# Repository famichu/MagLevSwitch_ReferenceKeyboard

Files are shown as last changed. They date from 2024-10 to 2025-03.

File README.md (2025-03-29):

# MagLev Switch Reference Keyboard
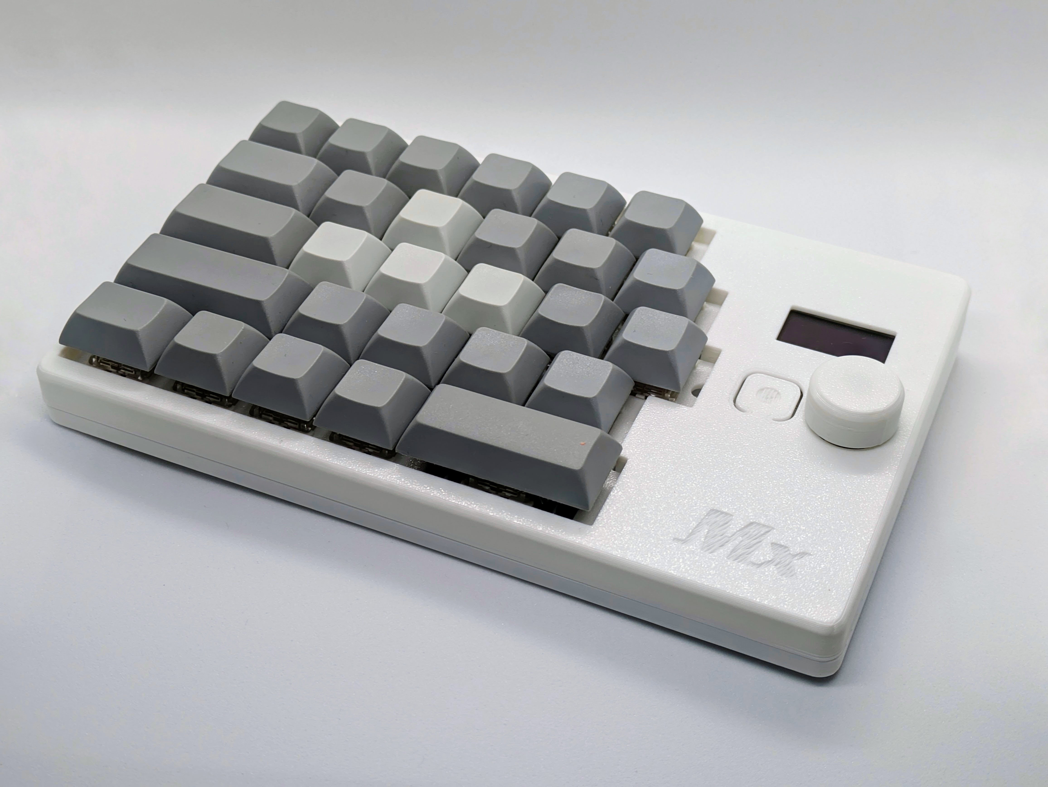
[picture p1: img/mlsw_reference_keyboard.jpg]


## Summary
This keyboard is a reference keyboard for using the MagLev switch, which has linear-output Hall effect sensors and magnetic levitation switches.

## Features
- A 28-switches keyboard for the left hand
- Uses 4 MagLev switches for the WASD keys
- Able to read the depth of the MagLev switches
- Built-in OLED displaying MagLev switch depth graphs

## BOM
### Main PCB
- Main PCB x1
- Kailh Switch Socket x24
- Cherry MX compatible switch x24
- MagLev Switch MX x4
- Stabilizer(2U) x2
- Incremental rotary encoder(PEC12R series of compatible) x1
- RP2040 x1
- Other small devices(refer to the schematic)

### Flex-PCB with OLED
- Flex-PCB x1
- OLED SSD1366 x1
- Other small devices(please refer the schematic)

###  Shell
- Top case(3D printed) x1
- Top plate(3D printed) x1
- knob(3D printed) x1
- Bottom case(3D printed) x1
- Stand(3D printed) x2
- Rubber foot(25mmx8mm oval) x2
- Bottom switch cap(3D printed) x1
- Screw M2x5mm x4
- Screw M2x8mm x4
- Insert nut M2x3mm(OD3.5mm) x8
- Cherry MX compatible keycap x28

## 3D Printing
Use FFF 3D printers to print shell parts. 

## PCB
I had manufactured at JLCPCB. The main PCB in this repository has an LCSC number as well.
This allows you to order the PCBA without selecting individual devices.

## Assembly
- 1. Solder all devices.
    
- 2. Insert switches through a top plate.
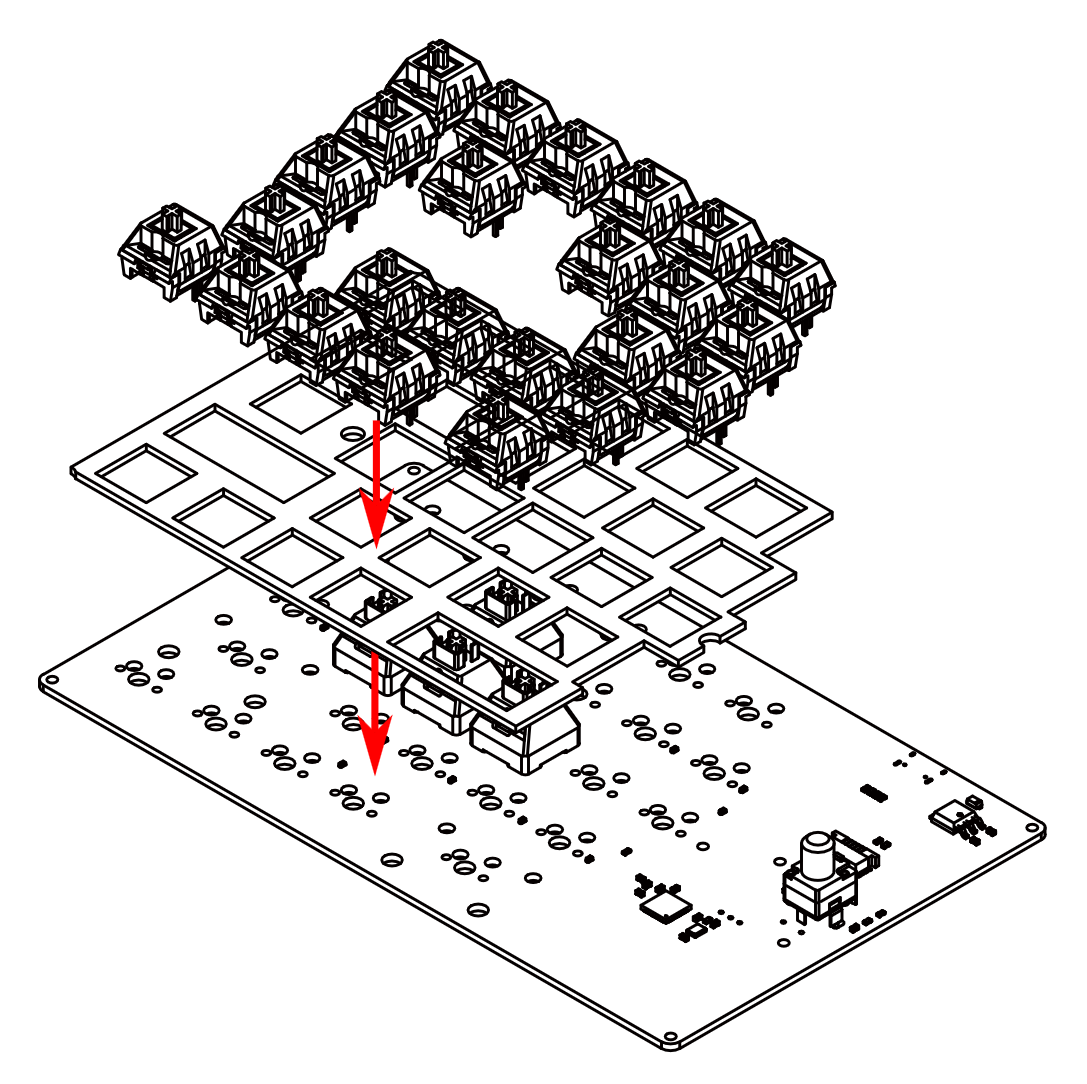
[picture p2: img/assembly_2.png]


- 3. Place the bottom switch cap onto the bottom case (Insert nuts into holes on the bottom plate if you print it by yourself.).
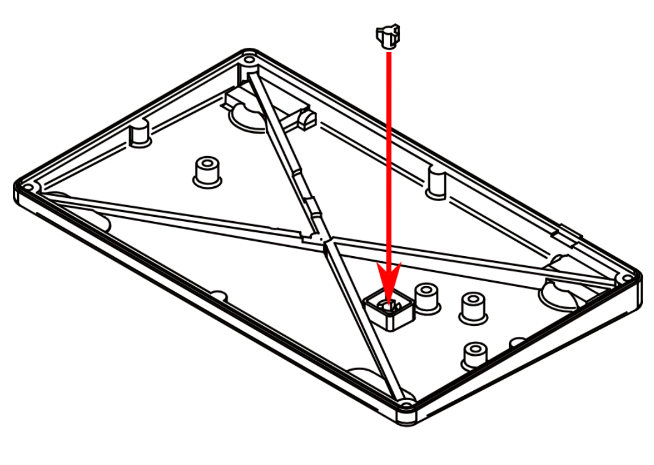
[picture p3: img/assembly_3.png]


- 4. Fix the PCB with screws.
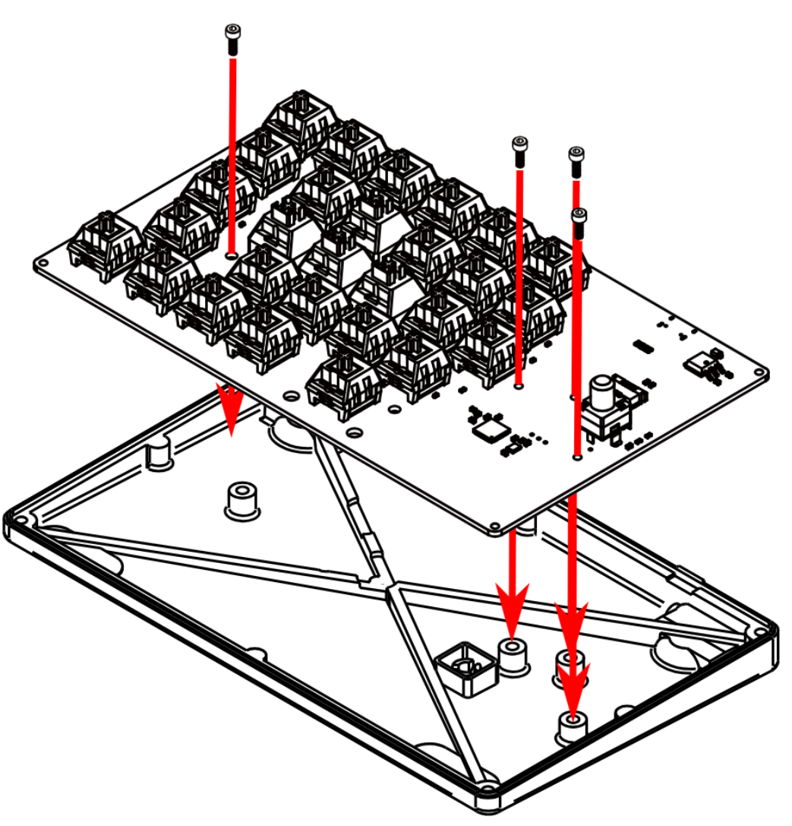
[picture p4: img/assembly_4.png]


- 5. Insert an OLED module with a flex PCB into the top case (Insert nuts into holes on the top plate if you print it by yourself).

- 6. Connect the flex-PCB with the main PCB.
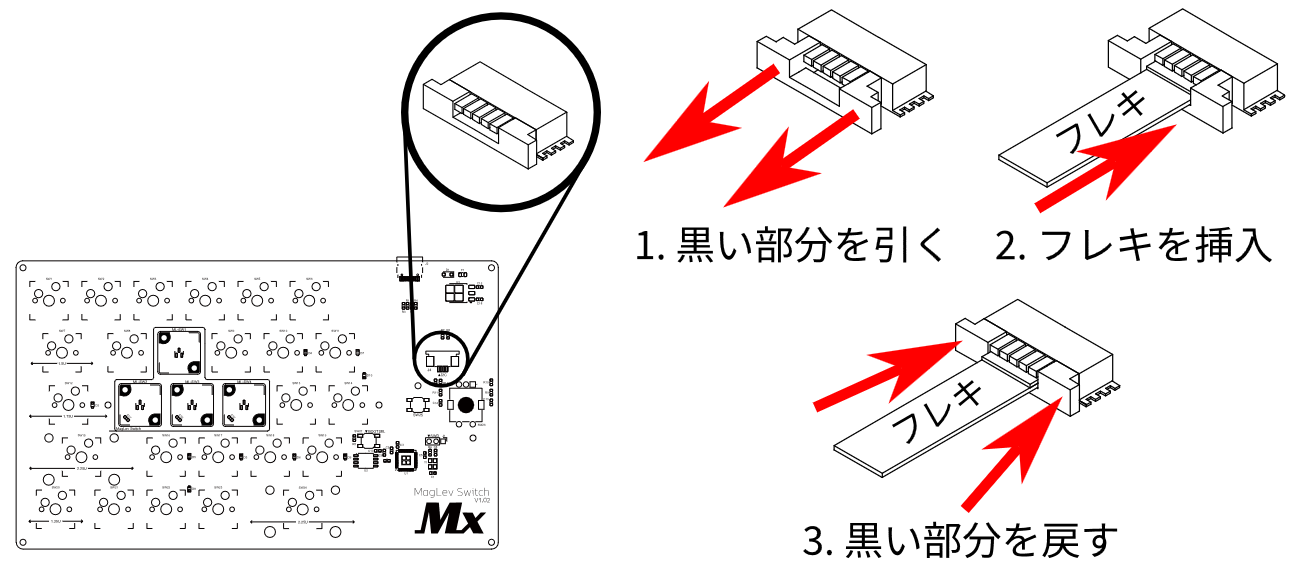
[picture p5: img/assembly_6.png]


- 7. Close the top and bottom cases with screws.
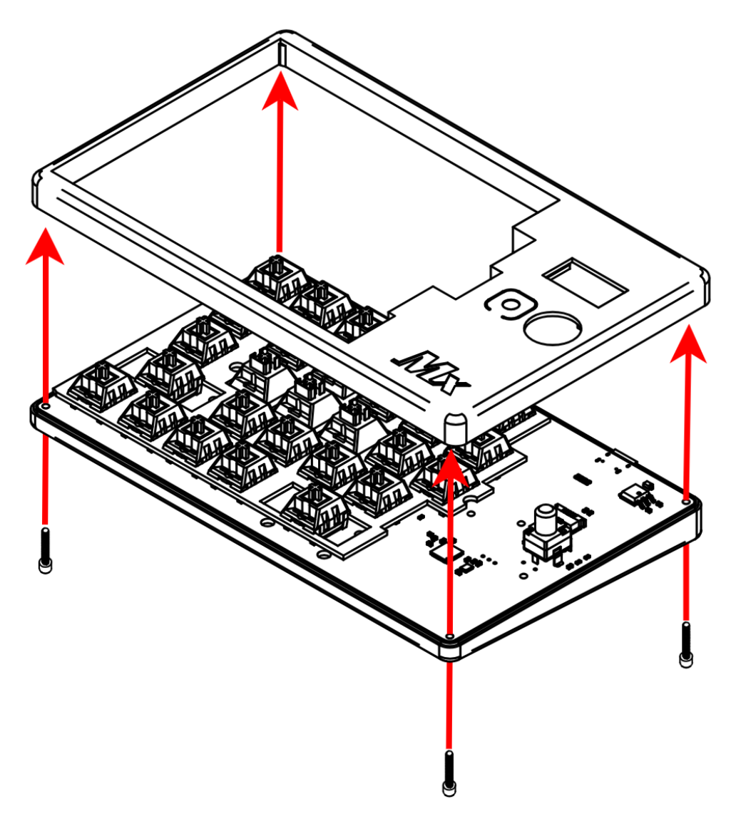
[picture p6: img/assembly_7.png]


- 8. Stick rubber feets.
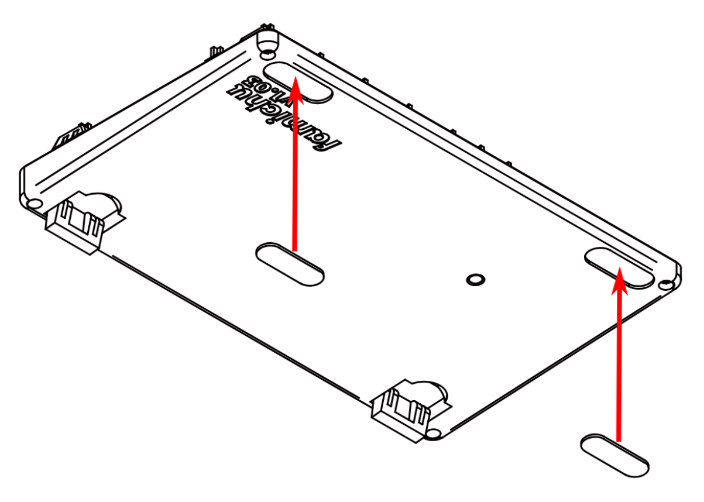
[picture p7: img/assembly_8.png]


- 9. Install keycaps and a knob.
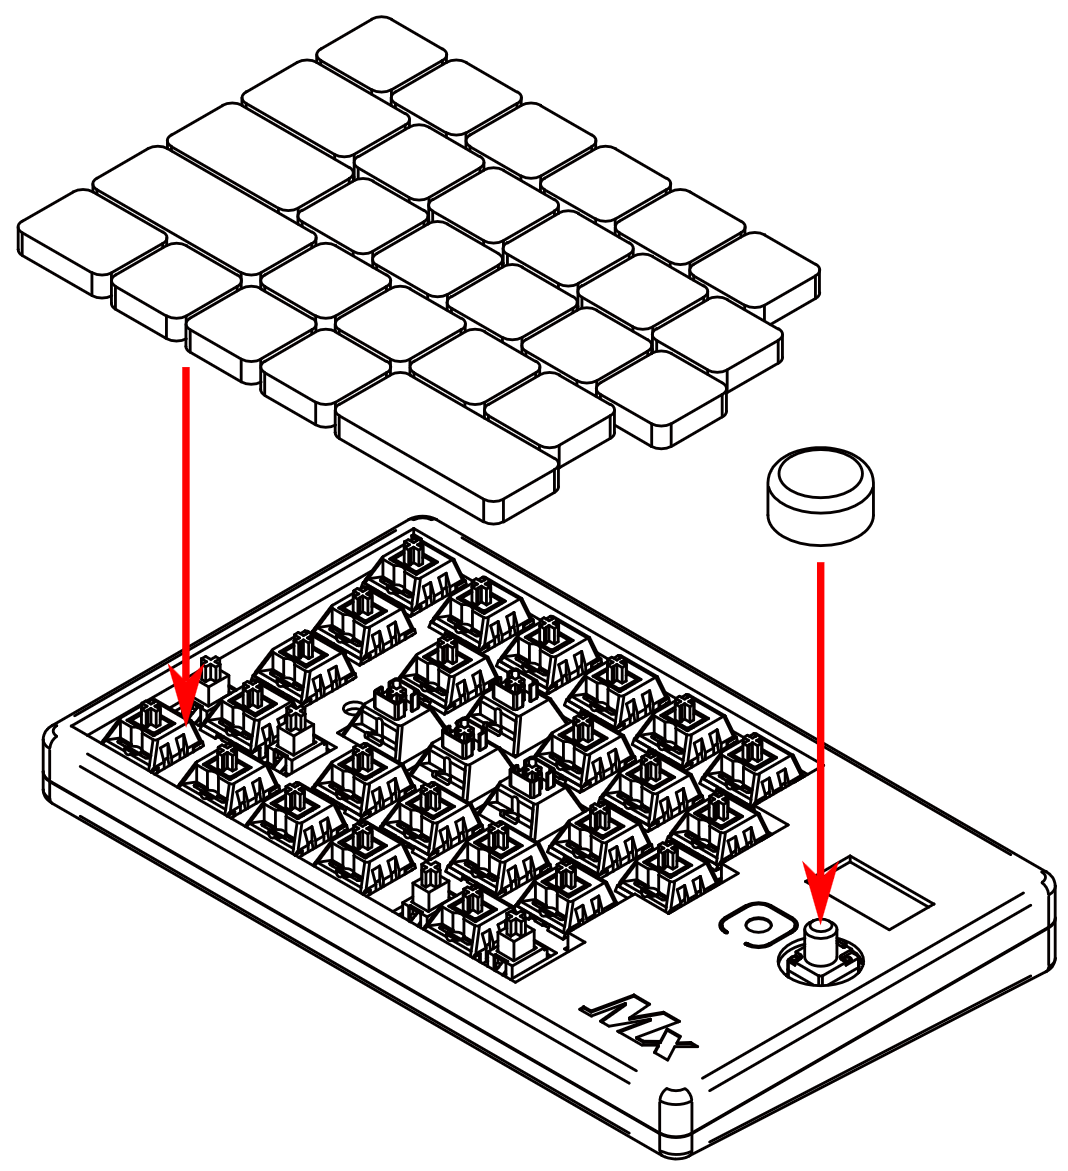
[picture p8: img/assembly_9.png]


- 10. Finish!
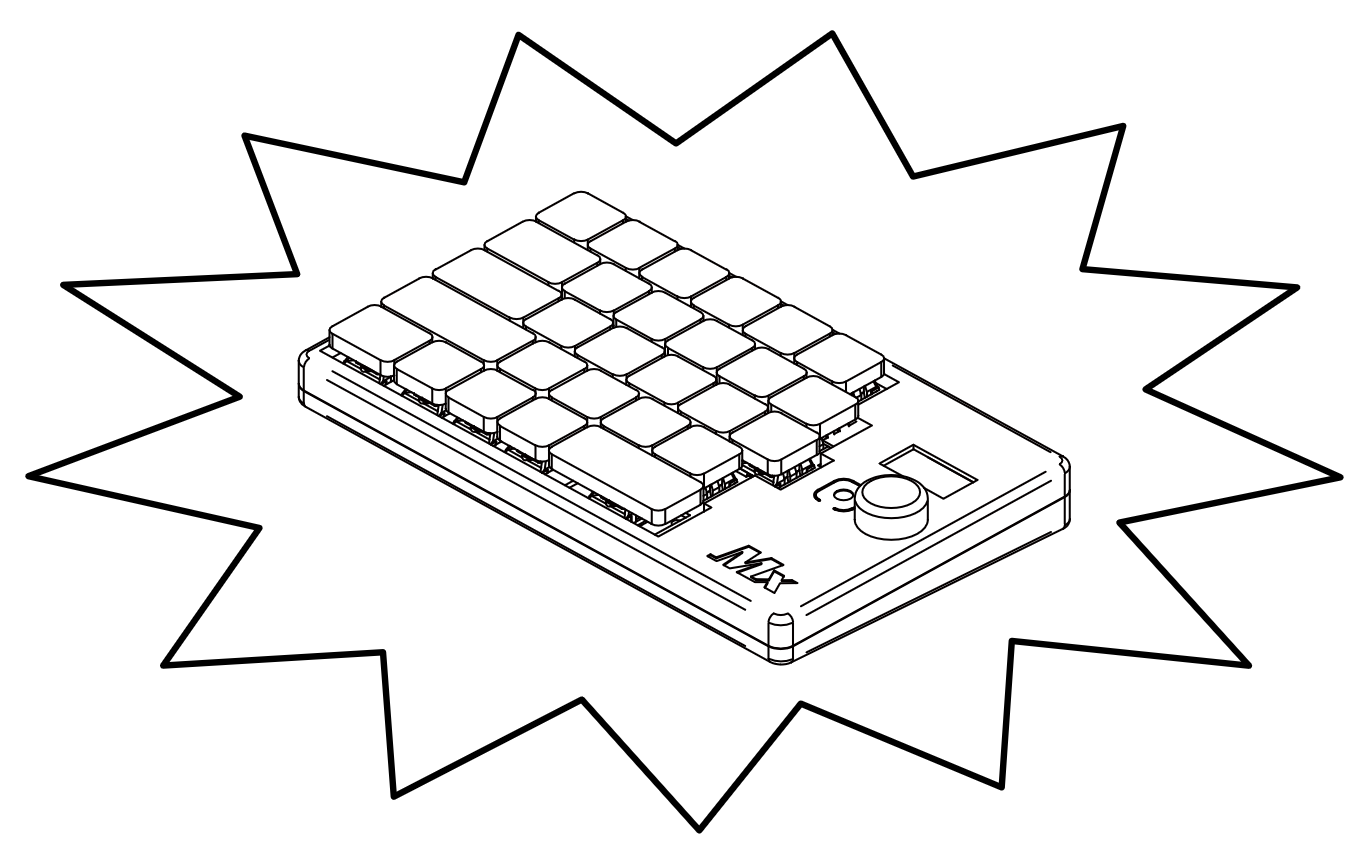
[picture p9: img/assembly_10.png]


# Directory configuration
- bin: Binary of the firmware
- pcb: Schematics & PCB artworks
    - libs: PCB libraries
    - Reference_Keyboard: Main PCB
    - SSD1366_FFC_Adapter: Flex-PCB with OLED
- shell: 3D models for FFF printer
- src: Source codes of the firmware

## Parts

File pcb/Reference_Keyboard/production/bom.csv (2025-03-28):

Designator | Footprint | Quantity | Value | LCSC Part #
C1, C8 | 0603 | 2 | 5.6p
C10, C11, C12, C16, C17, C2, C3, C4, C5, C7 | 0603 | 10 | 0.1u
C13, C14 | 0603 | 2 | 0.01u
C15, C18 | 0603 | 2 | 10u
C9 | 0603 | 1 | 2.2u
D1 | D_SOD-123F | 1 | RB161MM-20TR | C123070
D10, D2, D3, D4, D5, D6, D7, D8, D9 | D_SOD-523 | 9 | 1SS387 | C146426
F1 | 0805 | 1 | Polyfuse | C524650
H1, H2, H3, H4, H5, H6, H7, H8 | MountingHole_2.2mm_M2 | 8 | MountingHole
J2 | USB_C_Receptacle_HRO_TYPE-C-31-M-12 | 1 | USB_C_Receptacle_USB2.0 | C165948
J4 | TE_84953-4_1x04-1MP_P1.0mm_Horizontal | 1 | 84953-4 | C590896
ML-SW1, ML-SW2, ML-SW3, ML-SW4 | MagLevSwitch_Up | 4 | MagLevSwich
R1, R2 | 0603 | 2 | 27
R10, R11, R12, R9 | 0603 | 4 | 10k
R3, R4 | 0603 | 2 | 5.1k
R5, R6, R7, R8 | 0603 | 4 | 1k
SW1, SW10, SW11, SW13, SW14, SW16, SW17, SW18, SW19, SW2, SW21, SW22, SW23, SW3, SW4, SW5, SW6, SW8, SW9 | MX-Hotswap-1U | 19 | SW_Push
SW12 | MX-Hotswap-1.75U | 1 | SW_Push
SW15, SW24 | MX-Hotswap-2.25U | 2 | SW_Push
SW20 | MX-Hotswap-1.25U | 1 | SW_Push
SW25, SW27, SW28 | SW_SPST_SKQG_WithStem | 3 | SKQGAFE010 | C202424
SW26 | RotaryEncoder_Alps_EC11E-Switch_Vertical_H20mm | 1 | RotaryEncoder_Switch
SW7 | MX-Hotswap-1.5U | 1 | SW_Push
TP1 | TestPoint_Pad_D1.5mm | 1 | Conn_01x01_Pin
U1 | QFN-56-1EP_7x7mm_P0.4mm_EP3.2x3.2mm | 1 | RP2040 | C2040
U2 | SOIC-8_5.23x5.23mm_P1.27mm | 1 | W25Q16JVSSIM | C82317
U3 | TO-252-3_TabPin2 | 1 | LM1117RS-3.3 | C126023
Y1 | Crystal_SMD_3225-4Pin_3.2x2.5mm | 1 | NX3225SA-12MHz-STD-CSR-6 | C481400

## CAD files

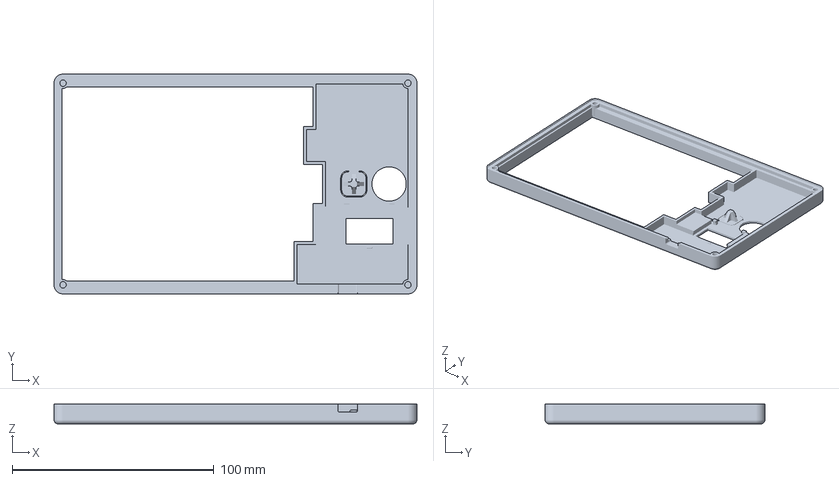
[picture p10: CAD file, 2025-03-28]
shell/TopCase.3mf
180.0 x 109.0 x 9.80 mm

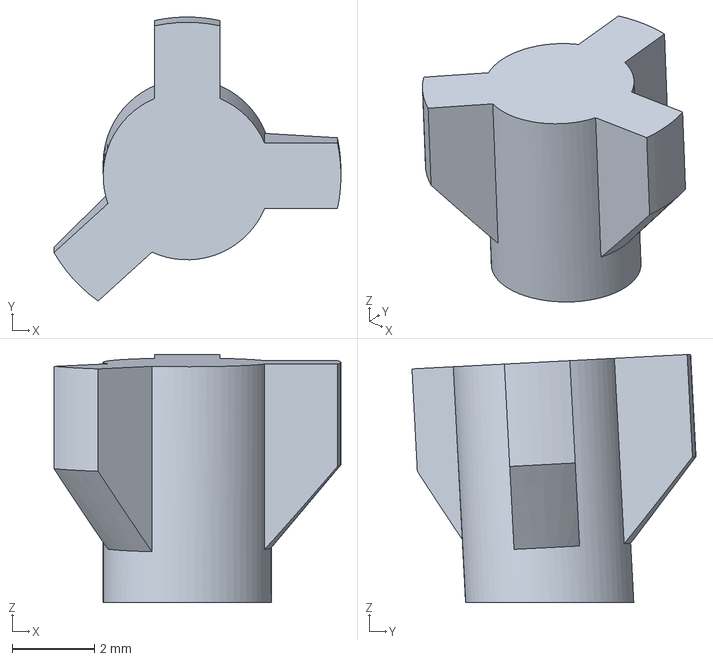
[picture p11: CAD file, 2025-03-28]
shell/BottomSwitchCap.3mf
7.00 x 6.93 x 6.06 mm

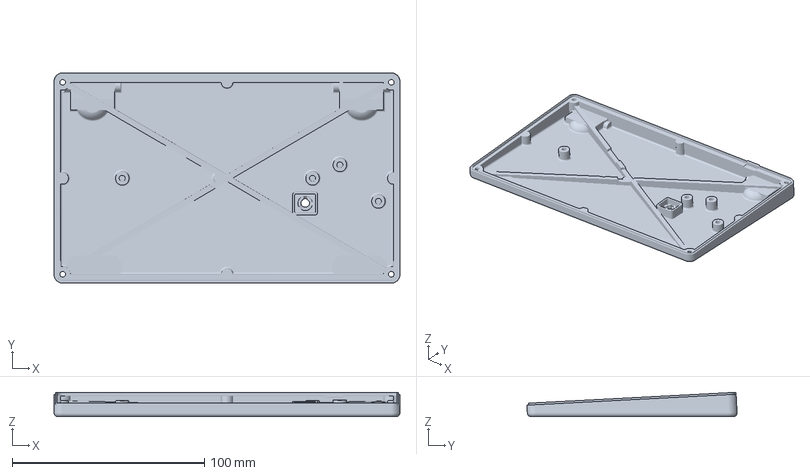
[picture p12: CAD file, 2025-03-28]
shell/BottomCase.3mf
180.0 x 109.4 x 12.7 mm

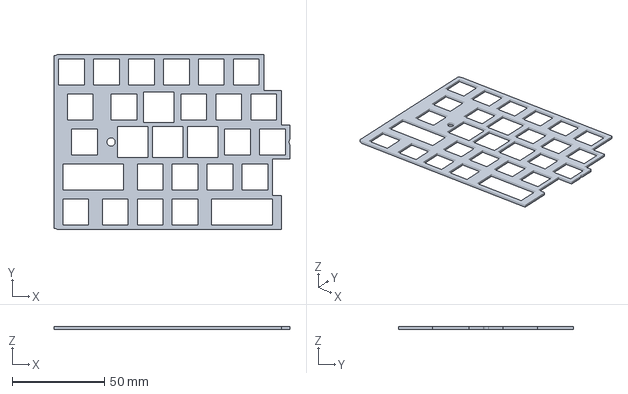
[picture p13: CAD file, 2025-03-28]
shell/TopPlate.3mf
128.2 x 95.0 x 1.60 mm

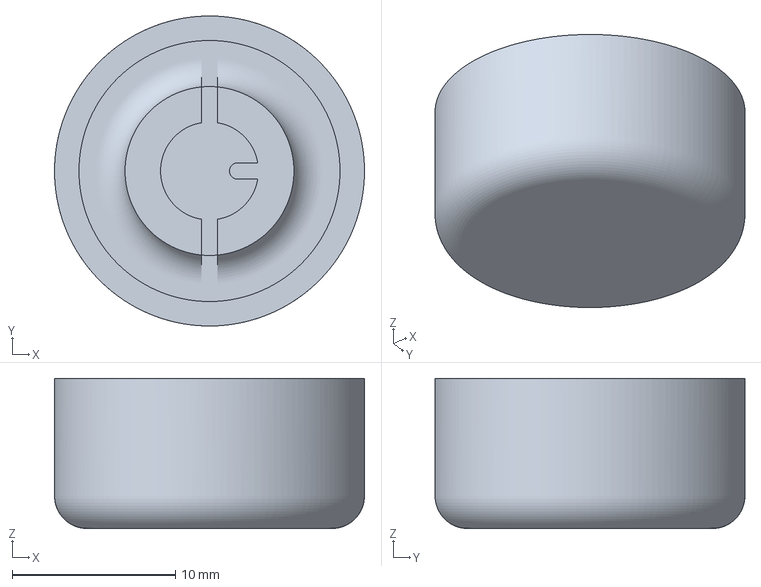
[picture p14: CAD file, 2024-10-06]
shell/Knob.3mf
19.0 x 19.0 x 9.20 mm

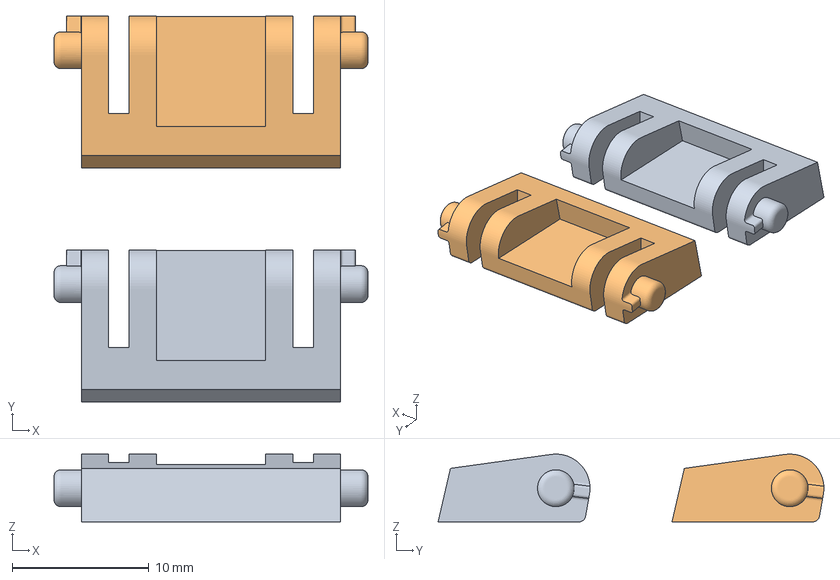
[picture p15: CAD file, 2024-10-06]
shell/Stand.3mf
23.0 x 28.3 x 4.96 mm
Case1.1 v7_1_2
Case1.1 v7_1_3

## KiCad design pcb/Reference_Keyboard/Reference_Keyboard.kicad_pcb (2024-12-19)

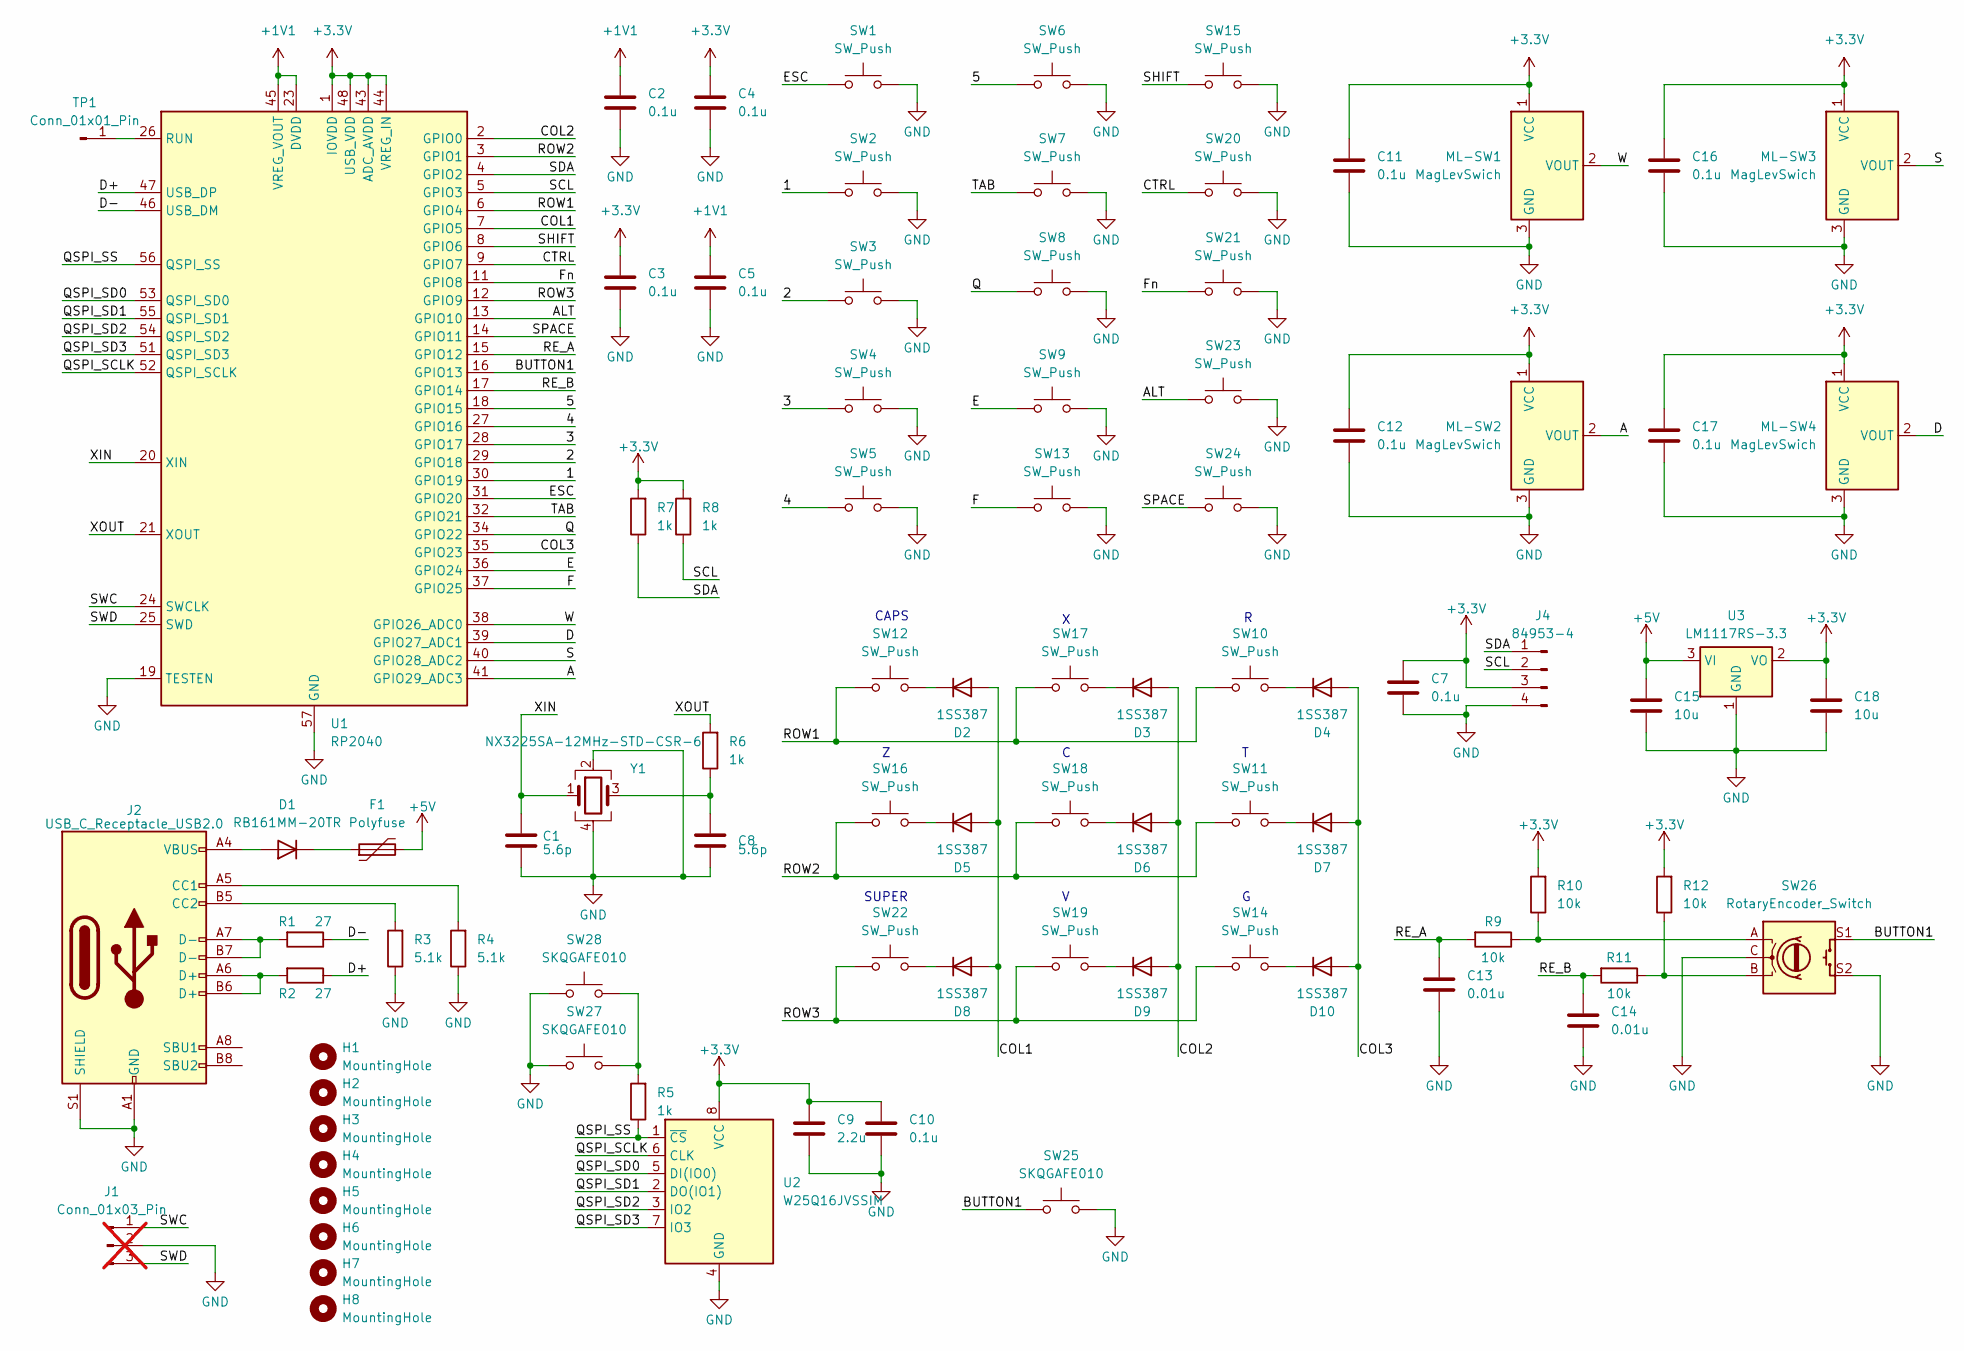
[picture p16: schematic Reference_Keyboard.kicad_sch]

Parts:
C1, C8: 5.6p; C_0603_1608Metric
C2, C3, C4, C5, C7, C10, C11, C12, C16, C17: 0.1u; C_0603_1608Metric
C9: 2.2u; C_0603_1608Metric
C13, C14: 0.01u; C_0603_1608Metric
C15, C18: 10u; C_0603_1608Metric
D1: RB161MM-20TR; D_SOD-123F; LCSC C123070
D2, D3, D4, D5, D6, D7, D8, D9, D10: 1SS387; D_SOD-523; LCSC C146426
F1: Polyfuse; Fuse_0805_2012Metric
H1, H2, H3, H4, H5, H6, H7, H8: MountingHole; MountingHole_2.2mm_M2
J1: Conn_01x03_Pin; PinHeader_1x03_P2.54mm_Vertical; not fitted
J2: USB_C_Receptacle_USB2.0; USB_C_Receptacle_HRO_TYPE-C-31-M-12; LCSC C165948
J4: 84953-4; TE_84953-4_1x04-1MP_P1.0mm_Horizontal; LCSC C590896
ML-SW1, ML-SW2, ML-SW3, ML-SW4: MagLevSwich; MagLevSwitch_Up
R1, R2: 27; R_0603_1608Metric
R3, R4: 5.1k; R_0603_1608Metric
R5, R6, R7, R8: 1k; R_0603_1608Metric
R9, R10, R11, R12: 10k; R_0603_1608Metric
SW1, SW2, SW3, SW4, SW5, SW6, SW8, SW9, SW10, SW11, SW13, SW14, SW16, SW17, SW18, SW19, SW21, SW22, SW23: SW_Push; MX-Hotswap-1U
SW7: SW_Push; MX-Hotswap-1.5U
SW12: SW_Push; MX-Hotswap-1.75U
SW15, SW24: SW_Push; MX-Hotswap-2.25U
SW20: SW_Push; MX-Hotswap-1.25U
SW25, SW27, SW28: SKQGAFE010; SW_SPST_SKQG_WithStem; LCSC C202424
SW26: RotaryEncoder_Switch; RotaryEncoder_Alps_EC11E-Switch_Vertical_H20mm
TP1: Conn_01x01_Pin; TestPoint_Pad_D1.5mm
U1: RP2040; QFN-56-1EP_7x7mm_P0.4mm_EP3.2x3.2mm; LCSC C2040
U2: W25Q16JVSSIM; SOIC-8_5.23x5.23mm_P1.27mm; LCSC C82317
U3: LM1117RS-3.3; TO-252-3_TabPin2; LCSC C126023
Y1: NX3225SA-12MHz-STD-CSR-6; Crystal_SMD_3225-4Pin_3.2x2.5mm; LCSC C481400

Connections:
+1V1: C2.1, C5.1, U1.23 (DVDD), U1.45 (VREG_VOUT), U1.50 (DVDD)
+3.3V: C3.1, C4.1, C7.1, C9.1, C10.1, C11.1, C12.1, C16.1, C17.1, C18.1, J4.3, ML-SW1.1 (VCC), ML-SW2.1 (VCC), ML-SW3.1 (VCC), ML-SW4.1 (VCC), R7.2, R8.2, R10.2, R12.2, U1.1 (IOVDD), U1.10 (IOVDD), U1.22 (IOVDD), U1.33 (IOVDD), U1.42 (IOVDD), U1.43 (ADC_AVDD), U1.44 (VREG_IN), U1.48 (USB_VDD), U1.49 (IOVDD), U2.8 (VCC), U3.2 (VO)
+5V: C15.1, F1.2, U3.3 (VI)
/1: SW2.1, U1.30 (GPIO19)
/2: SW3.1, U1.29 (GPIO18)
/3: SW4.1, U1.28 (GPIO17)
/4: SW5.1, U1.27 (GPIO16)
/5: SW6.1, U1.18 (GPIO15)
/A: ML-SW2.2 (VOUT), U1.41 (GPIO29_ADC3)
/ALT: SW23.1, U1.13 (GPIO10)
/BUTTON1: SW25.1, SW26.S1, U1.16 (GPIO13)
/COL1: D2.2 (A), D5.2 (A), D8.2 (A), U1.7 (GPIO5)
/COL2: D3.2 (A), D6.2 (A), D9.2 (A), U1.2 (GPIO0)
/COL3: D4.2 (A), D7.2 (A), D10.2 (A), U1.35 (GPIO23)
/CTRL: SW20.1, U1.9 (GPIO7)
/D: ML-SW4.2 (VOUT), U1.39 (GPIO27_ADC1)
/D+: R2.1, U1.47 (USB_DP)
/D-: R1.1, U1.46 (USB_DM)
/E: SW9.1, U1.36 (GPIO24)
/ESC: SW1.1, U1.31 (GPIO20)
/F: SW13.1, U1.37 (GPIO25)
/Fn: SW21.1, U1.11 (GPIO8)
/Q: SW8.1, U1.34 (GPIO22)
/QSPI_SCLK: U1.52 (QSPI_SCLK), U2.6 (CLK)
/QSPI_SD0: U1.53 (QSPI_SD0), U2.5 (DI(IO0))
/QSPI_SD1: U1.55 (QSPI_SD1), U2.2 (DO(IO1))
/QSPI_SD2: U1.54 (QSPI_SD2), U2.3 (IO2)
/QSPI_SD3: U1.51 (QSPI_SD3), U2.7 (IO3)
/QSPI_SS: R5.1, U1.56 (QSPI_SS), U2.1 (~CS)
/RE_A: C13.1, R9.2, U1.15 (GPIO12)
/RE_B: C14.1, R11.2, U1.17 (GPIO14)
/ROW1: SW10.1, SW12.1, SW17.1, U1.6 (GPIO4)
/ROW2: SW11.1, SW16.1, SW18.1, U1.3 (GPIO1)
/ROW3: SW14.1, SW19.1, SW22.1, U1.12 (GPIO9)
/S: ML-SW3.2 (VOUT), U1.40 (GPIO28_ADC2)
/SCL: J4.2, R8.1, U1.5 (GPIO3)
/SDA: J4.1, R7.1, U1.4 (GPIO2)
/SHIFT: SW15.1, U1.8 (GPIO6)
/SPACE: SW24.1, U1.14 (GPIO11)
/SWC: J1.1, U1.24 (SWCLK)
/SWD: J1.3, U1.25 (SWD)
/TAB: SW7.1, U1.32 (GPIO21)
/W: ML-SW1.2 (VOUT), U1.38 (GPIO26_ADC0)
/XIN: C1.1, U1.20 (XIN), Y1.1
/XOUT: R6.2, U1.21 (XOUT)
GND: C1.2, C2.2, C3.2, C4.2, C5.2, C7.2, C8.2, C9.2, C10.2, C11.2, C12.2, C13.2, C14.2, C15.2, C16.2, C17.2, C18.2, J1.2, J2.A1 (GND), J2.A12 (GND), J2.B1 (GND), J2.B12 (GND), J2.S1 (SHIELD), J4.4, ML-SW1.3 (GND), ML-SW2.3 (GND), ML-SW3.3 (GND), ML-SW4.3 (GND), R3.1, R4.1, SW1.2, SW2.2, SW3.2, SW4.2, SW5.2, SW6.2, SW7.2, SW8.2, SW9.2, SW13.2, SW15.2, SW20.2, SW21.2, SW23.2, SW24.2, SW25.2, SW26.C, SW26.S2, SW27.1, SW28.1, U1.19 (TESTEN), U1.57 (GND), U2.4 (GND), U3.1 (GND), Y1.2, Y1.4
unnamed: C8.1, R6.1, Y1.3
unnamed: D1.2 (A), J2.A4 (VBUS), J2.A9 (VBUS), J2.B4 (VBUS), J2.B9 (VBUS)
unnamed: D1.1 (K), F1.1
unnamed: D2.1 (K), SW12.2
unnamed: D3.1 (K), SW17.2
unnamed: D4.1 (K), SW10.2
unnamed: D5.1 (K), SW16.2
unnamed: D6.1 (K), SW18.2
unnamed: D7.1 (K), SW11.2
unnamed: D8.1 (K), SW22.2
unnamed: D9.1 (K), SW19.2
unnamed: D10.1 (K), SW14.2
unnamed: J2.A5 (CC1), R4.2
unnamed: J2.B5 (CC2), R3.2
unnamed: J2.A6 (D+), J2.B6 (D+), R2.2
unnamed: J2.A7 (D-), J2.B7 (D-), R1.2
unnamed: R5.2, SW27.2, SW28.2
unnamed: R9.1, R10.1, SW26.A
unnamed: R11.1, R12.1, SW26.B
unnamed: TP1.1, U1.26 (RUN)

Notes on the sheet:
SUPER
CAPS

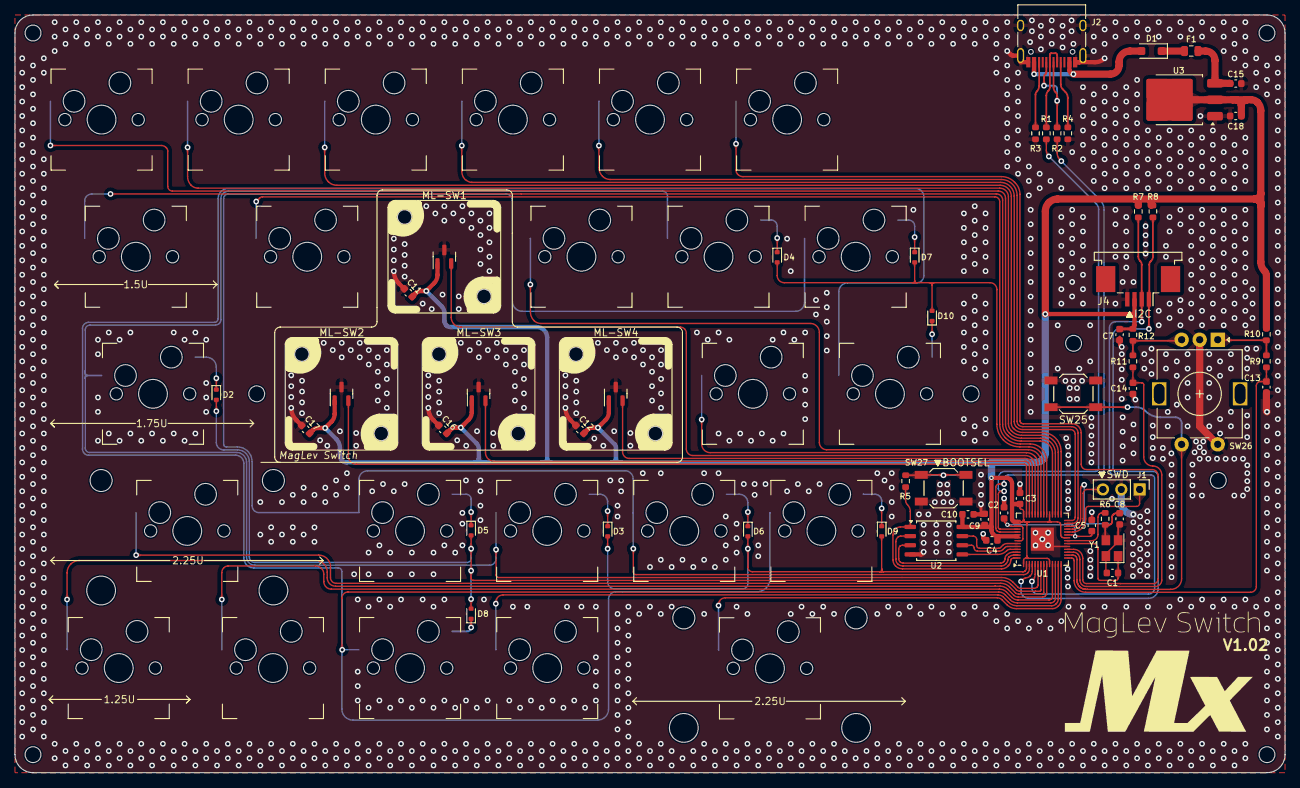
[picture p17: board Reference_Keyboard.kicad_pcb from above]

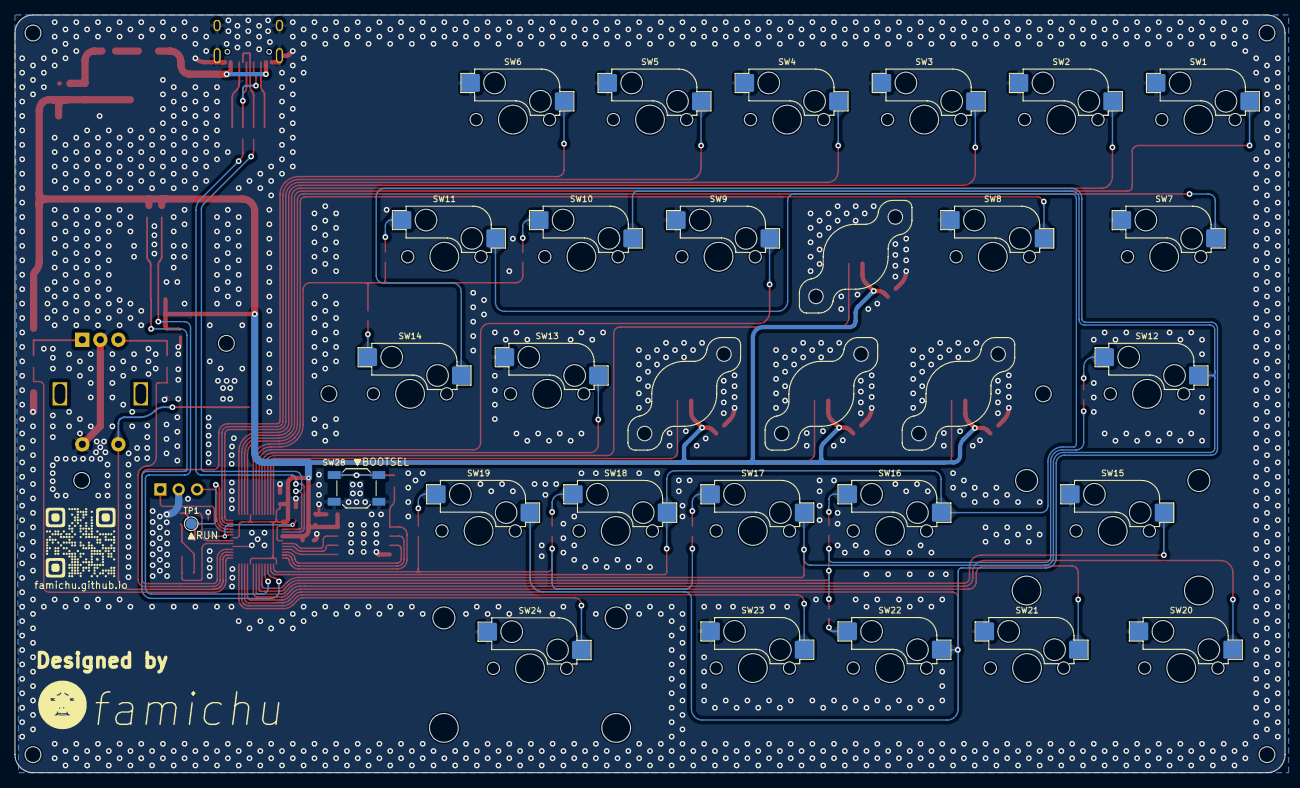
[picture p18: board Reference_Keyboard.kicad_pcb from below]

Board: 2 copper layers, 176.0 x 105.0 mm, 88 parts (2 on the bottom side), 66 nets.

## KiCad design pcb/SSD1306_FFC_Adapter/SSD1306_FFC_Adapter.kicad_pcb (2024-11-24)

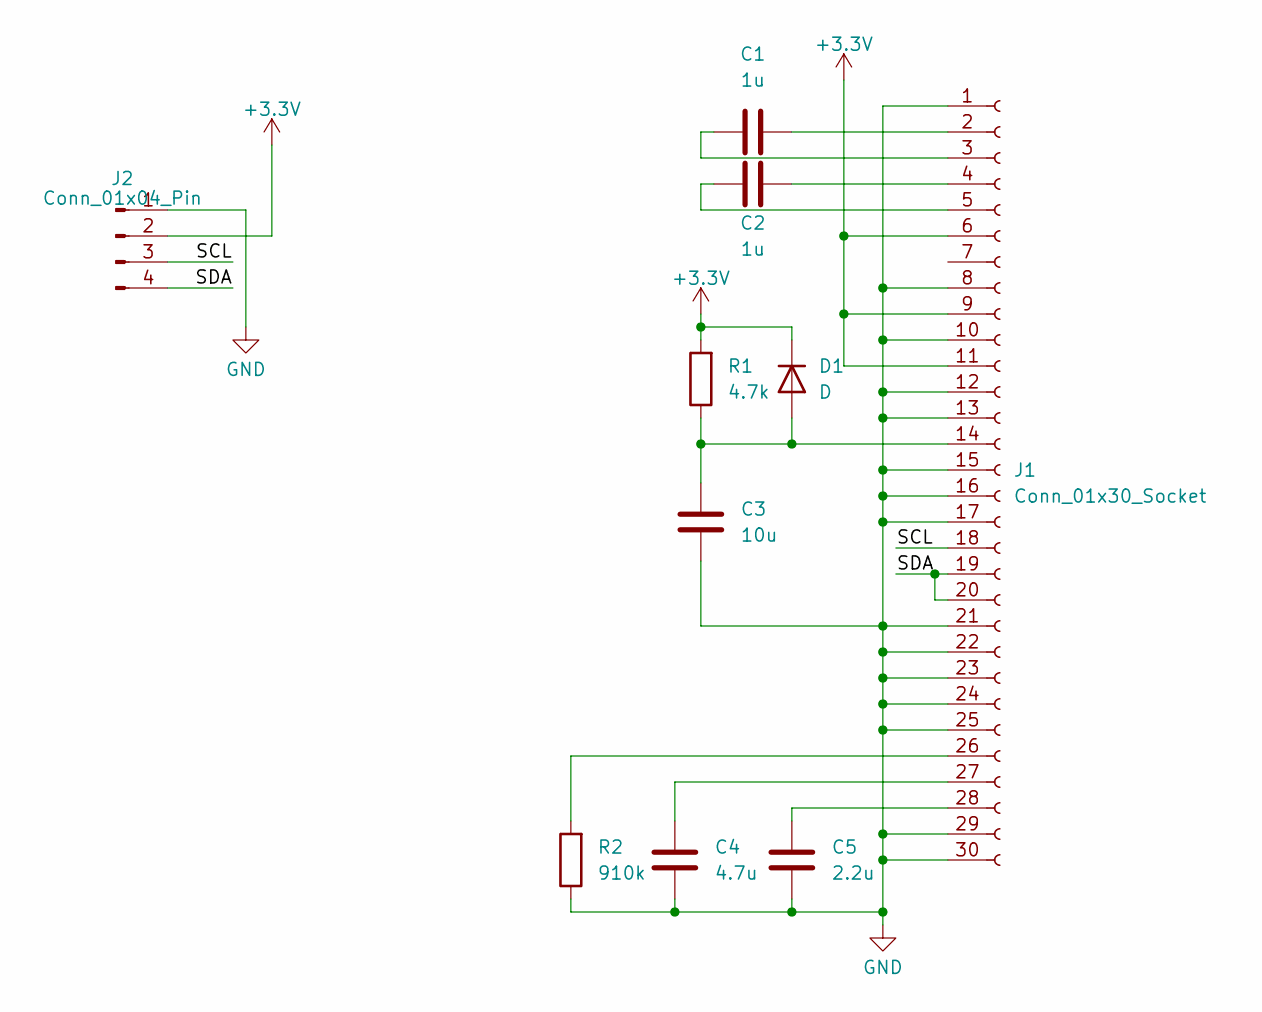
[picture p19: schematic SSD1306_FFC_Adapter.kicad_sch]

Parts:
C1, C2: 1u; C_0603_1608Metric
C3: 10u; C_0603_1608Metric
C4: 4.7u; C_0603_1608Metric
C5: 2.2u; C_0603_1608Metric
D1: D; D_0603_1608Metric
J1: Conn_01x30_Socket; OLED-128O064D
J2: Conn_01x04_Pin; FFC-FPC_1mm_1x04
R1: 4.7k; R_0603_1608Metric
R2: 910k; R_0603_1608Metric

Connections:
+3.3V: D1.1 (K), J1.6, J1.9, J1.11, J2.2, R1.2
/SCL: J1.18, J2.3
/SDA: J1.19, J1.20, J2.4
GND: C3.1, C4.1, C5.1, J1.1, J1.8, J1.10, J1.12, J1.13, J1.15, J1.16, J1.17, J1.21, J1.22, J1.23, J1.24, J1.25, J1.29, J1.30, J2.1, R2.1
unnamed: C3.2, D1.2 (A), J1.14, R1.1
unnamed: C1.2, J1.2
unnamed: C1.1, J1.3
unnamed: C2.2, J1.4
unnamed: C2.1, J1.5
unnamed: J1.26, R2.2
unnamed: C4.2, J1.27
unnamed: C5.2, J1.28

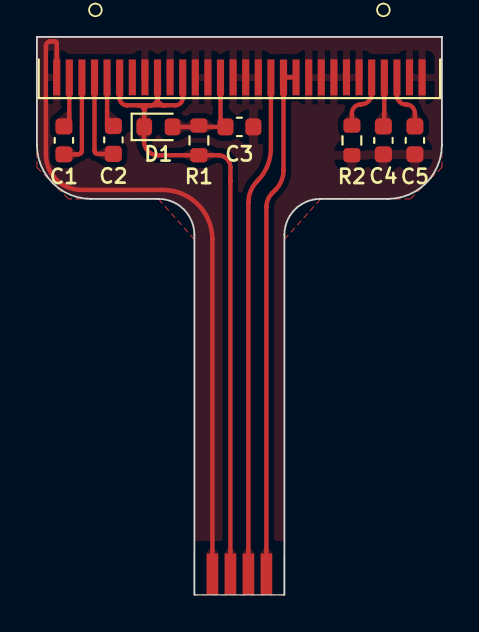
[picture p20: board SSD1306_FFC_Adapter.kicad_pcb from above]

Board: 2 copper layers, 22.5 x 31.0 mm, 10 parts (0 on the bottom side), 12 nets.

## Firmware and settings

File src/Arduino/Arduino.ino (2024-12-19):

#include "MaglevSwitch_Board.h"
#include <cstdint>
#include "pico/stdlib.h"
#include "hardware/adc.h"
#include "hardware/gpio.h"
#include "hardware/i2c.h"
#include <Wire.h>
#include <Adafruit_GFX.h>
#include <Adafruit_SSD1306.h>
#include "Adafruit_TinyUSB.h"
#include "hid/Adafruit_USBD_HID.h"
#include "BarGraph.h"
#include "Setting.h"
#include "Demo.h"

// #define DISPLAY_DEBUG // Showing the debugging screen
#define DEMO_MODE

// Display
#define SCREEN_WIDTH 128 // OLED display width, in pixels
#define SCREEN_HEIGHT 64 // OLED display height, in pixels

i2c_inst_t *i2c = i2c1;
TwoWire myWire(i2c, 2, 3);
Adafruit_SSD1306 display(SCREEN_WIDTH, SCREEN_HEIGHT, &myWire, -1);

#define NUM_BARS 4
BarGraph graph(SCREEN_WIDTH, SCREEN_HEIGHT, NUM_BARS);

// USB HID
Adafruit_USBD_HID usb_hid;

uint8_t const desc_hid_report[] = {
  TUD_HID_REPORT_DESC_KEYBOARD()
};


// Rotary encoder
volatile uint64_t lastInterruptTimeUs = 0; 
static uint64_t debounceDelayUs = 1500; // Debounce delay time(us)
volatile EncoderConditions encoderConditions;
void encoderInterrupt(void); // Prototype


// Semaphoere
static semaphore_t semaphoere;

static uint8_t SwVersion = 101;
uint16_t HwVersion = 0;

// MagLevSwitch Thresholds
// prototype
float calcNormalizedValue(uint16_t);
float calcAbsoluteValue(uint16_t);

// Output char codes array
uint8_t outCodes[6] = {0};

// Current oled state
int8_t G_OLEDSTATE = -1;


MaglevSwitchBoard* board = nullptr;
Setting setting = Setting(101);
Config config;

uint8_t G_LOADED = 0;


void setup() {
  i2c_init(i2c, 400 * 1000);
  display.begin(SSD1306_SWITCHCAPVCC, 0x3C);
  
  #ifndef DEMO_MODE
  hid_init();
  #endif
  #ifdef DEMO_MODE
  eraseSettings();
  #endif

  resetWizard();

  if(setting.Initialize() == false) {
    calibrationWizard();
  }
  config = setting.getConfig();

  board = new MaglevSwitchBoard(config.HardwareVersion, config.KeymapL1, config.KeymapL2, 
      config.ActuationThresholds, config.ReleaseThresholds, outCodes);

  showLogo();

  attachInterrupt(digitalPinToInterrupt(ENCODER_A), encoderInterrupt, RISING);

  sem_init(&semaphoere, 1, 1);
  multicore_launch_core1(pollingLoop);
}

void loop() {
  const uint32_t intervalMs = 50;
  uint32_t prevMs           = 0;
  uint32_t currentMs        = 0;

  uint8_t cnt         = 0;
  uint8_t codes[6]    = {0};

  uint16_t values[4]  = {0};
  float normalizedValue[4] = {0.0};

  bool pressed        = false;
  bool pressedPrev    = false;

  static uint8_t oledstatePrev = 0;

  while(1){
    pressedPrev   = pressed;
    currentMs     = to_ms_since_boot(get_absolute_time());

    sem_acquire_blocking(&semaphoere);
    
    cnt = board->outCodesCnt();
    memcpy(&codes, &outCodes, 6);
    for(int i = 0; i < 4; i++){
      values[i] = board->currentMaglevValue(i);
    }
 
    if(currentMs - prevMs >= intervalMs){
      prevMs  = currentMs;
      pressed = board->encoderPressed();
    }

    sem_release(&semaphoere);

    #if !defined(DEMO_MODE)
    hid_task(codes, cnt);
    #endif
    
    #ifdef DISPLAY_DEBUG
    for(uint8_t i = 0; i < cnt; i++){
      codes[i] = codes[i] + 61;
    }
    #endif
    
   for(int i = 0; i < 4; i++){
     normalizedValue[i] = calcNormalizedValue(values[i]);
   }

   if(pressed & !pressedPrev){
     G_OLEDSTATE++;

     if(G_OLEDSTATE == 9){
         sem_acquire_blocking(&semaphoere);
         setting.Save(config);
         sem_release(&semaphoere);
         break;
     }

     if(G_OLEDSTATE > 8){
       G_OLEDSTATE = -1;
     }
     oledstatePrev = G_OLEDSTATE;
   }

    updateOled(codes, cnt, normalizedValue, encoderConditions.position, G_OLEDSTATE);
  }
}

void pollingLoop(void){
  const uint64_t intervalUs = 1000;
  static uint64_t startUs   = 0;
  
  while(1){
    if(to_us_since_boot(get_absolute_time()) - startUs < intervalUs){
      continue;
    }
    startUs += intervalUs;
    
    sem_acquire_blocking(&semaphoere);
    board->updateState();
    sem_release(&semaphoere);
  }
}

void updateOled(uint8_t* codes, uint8_t cnt, float values[4], double position, int8_t oledState){
  static int8_t prevOledState = -1;

  if(oledState == -1){
    if(prevOledState != -1){
      showLogo();
    }
  }
  else{
    display.clearDisplay();

    #ifdef DISPLAY_DEBUG
    display.setTextSize(1);
    display.setTextColor(WHITE);
    display.setCursor(0, 10);
    display.println("MagLev Switch MX");
    display.setCursor(100, 10);
    display.println(config.HardwareVersion);

   for(int i = 0; i < 4; i++){
     display.setCursor(0, (20 + 10 * i));
     display.println(calcAbsoluteValue(values[i]));
   }

   for(int i = 0; i < 4; i++){
     display.setCursor(30, (20 + 10 * i));
     display.println(config.ActuationThresholds[i].getAbsoluted());
   }
   
   for(int i = 0; i < 4; i++){
     display.setCursor(60, (20 + 10 * i));
     display.println(config.ReleaseThresholds[i].getAbsoluted());
   }
    
    display.setCursor(100, 20);
    display.println(position);
    
    display.setCursor(100, 30);
    display.println(oledState);

    display.setCursor(100, 40);
    display.println(cnt);
    
    display.setCursor(95, 50);
    char *charCodes = (char *)codes;
    display.println(charCodes);
    
    #else
    graph.cursor = oledState;
    for (int i = 0; i < NUM_BARS; ++i) {;
      graph.setBarValue(i,  values[i]);
      #if !defined(DEMO_MODE)
      graph.setBarThresholds(
        i, 
        config.ReleaseThresholds[i].getNormalized(),
        config.ActuationThresholds[i].getNormalized());
      #endif
    }
    graph.draw(display);
    
    #ifdef DEMO_MODE
    char *charCodes = (char *)codes;
    display.setTextSize(1);
    display.setTextColor(WHITE);
    
    for(uint8_t i = 0; i < cnt; i++){
      display.setCursor(0, 10 * i);
      uint8_t keyNum = getSwitchNum(charCodes[i]);
      display.println(keyNum);
    } 
    #endif
    #endif
    display.display();
  }

  prevOledState = oledState;
}

void showLogo(void){
  display.clearDisplay();
  display.drawXBitmap(0, 0, LOGO, 128, 64, 1);
  display.display();
}

void encoderInterrupt(void){
  uint64_t currentTimeUs = to_us_since_boot(get_absolute_time());

  if(currentTimeUs - lastInterruptTimeUs >= debounceDelayUs){
    lastInterruptTimeUs = currentTimeUs;
    if(digitalRead(ENCODER_B) == HIGH){
        encoderConditions.pulseCount--;
        increaseThreshold(G_OLEDSTATE, false);
    }
    else{
        encoderConditions.pulseCount++;
        increaseThreshold(G_OLEDSTATE, true);
    }
    
    if(encoderConditions.pulseCount >= 24){
      encoderConditions.pulseCount = 0;
    }
    else if(encoderConditions.pulseCount < 0){
      encoderConditions.pulseCount = 23;
    }
    encoderConditions.position = (double)(encoderConditions.pulseCount) / 23.0;
  }
}

void increaseThreshold(uint8_t state, bool increasing){
  uint8_t index = (state - 1) >> 1;
  uint8_t offset = (state - 1) & 1;
  
  uint16_t incremental = 0;
  if(increasing){
    incremental = MLSW_RANGE / 20;
  }
  else{
    incremental = -MLSW_RANGE / 20;
  }

  if(offset == 0) {
    uint16_t result = config.ActuationThresholds[index].getAbsoluted() + incremental;
    if(result < (MLSW_UPPER_LIMIT - 2) && result >= config.ReleaseThresholds[index].getAbsoluted()){
      config.ActuationThresholds[index].setAbsolute(result);
    }
    else if(result >= (MLSW_UPPER_LIMIT - 2)){
      config.ActuationThresholds[index].setAbsolute(MLSW_UPPER_LIMIT - 3);
    }
    else if(result < config.ReleaseThresholds[index].getAbsoluted()){
      config.ActuationThresholds[index].setAbsolute(config.ReleaseThresholds[index].getAbsoluted());
    }
  }
  else{
    uint16_t result = config.ReleaseThresholds[index].getAbsoluted() + incremental;
    if(result <= config.ActuationThresholds[index].getAbsoluted() && result > (MLSW_LOWER_LIMIT + 50)){
      config.ReleaseThresholds[index].setAbsolute(result);
    }
    else if(result > config.ActuationThresholds[index].getAbsoluted()){
      config.ReleaseThresholds[index].setAbsolute(config.ActuationThresholds[index].getAbsoluted());
    }
    else if(result <= (MLSW_LOWER_LIMIT + 50)){
      config.ReleaseThresholds[index].setAbsolute(MLSW_LOWER_LIMIT + 51);
    }
  }
}

void hid_init(){
  usb_hid.setBootProtocol(HID_ITF_PROTOCOL_KEYBOARD);
  usb_hid.setPollInterval(2);
  usb_hid.setReportDescriptor(desc_hid_report, sizeof(desc_hid_report));
  usb_hid.setStringDescriptor("TinyUSB Keyboard");
  usb_hid.begin();
  while( !TinyUSBDevice.mounted() ) delay(1);
}

void hid_task(uint8_t codes[6], uint8_t cnt){
  static bool keyPressedPreviously = false;
  if ( TinyUSBDevice.suspended() && cnt )
  {
    TinyUSBDevice.remoteWakeup();
  }

  if (!usb_hid.ready()) return;

  if (cnt)
  {
    uint8_t const report_id = 0;
    uint8_t const modifier  = 0;

    keyPressedPreviously = true;
    usb_hid.keyboardReport(report_id, modifier, codes);
  }
  else
  {
    if (keyPressedPreviously)
    {
      keyPressedPreviously = false;
      usb_hid.keyboardRelease(0);
    }
  }
}

float calcNormalizedValue(uint16_t value){
  float result = float(value - MLSW_LOWER_LIMIT) / (float)MLSW_RANGE;
  if(result > 1.00){
    result = 1.00;
  }
  else if(result < 0){
    result = 0.0;
  }
  return result;
}

uint16_t calcAbsoluteValue(float value){
  return uint16_t(value * MLSW_RANGE) + MLSW_LOWER_LIMIT;
}
 
void eraseSettings(){
  const uint32_t FLASH_TARGET_OFFSET = 0x1F0000; // The head address of the final block(block32) of the W25Q16JV: 0x1F0000
  
  uint32_t ints = save_and_disable_interrupts();
  flash_range_erase(FLASH_TARGET_OFFSET, FLASH_SECTOR_SIZE);
  restore_interrupts(ints);
}

void calibrationWizard(){
  calibrationGpioInit();
  #if !defined(DEMO_MODE)
  config = setting.Initialize(detectHwVersion());
  
  while(gpio_get(13)){
    delay(50);
  }

  clear_gpio(9);
  clear_gpio(23);
  clear_gpio(25);
  clear_gpio(13);
  #else
  config = setting.Initialize(101);
  #endif
  
  setting.Save(config);
}

void calibrationGpioInit(){
  // row 3 of the matrix on v1.01
  gpio_init(9);
  gpio_set_dir(9, GPIO_OUT);
  
  // col 3 of the matrix on v1.01
  gpio_init(23);
  gpio_pull_up(23);
  gpio_set_dir(23, GPIO_IN);
  
  // F key on the both version
  gpio_init(25);
  gpio_pull_up(25);
  gpio_set_dir(25, GPIO_IN);

  // A menu button
  gpio_init(13);
  gpio_pull_up(13);
  gpio_set_dir(13, GPIO_IN);
}

uint16_t detectHwVersion(){
  uint16_t result = 0;
  
  gpio_put(9, 0);
  absolute_time_t switching_delay_time = make_timeout_time_us(75);
  sleep_until(switching_delay_time);

  display.clearDisplay();
  display.setTextColor(WHITE);
  display.setCursor(0, 10);
  display.println("Calibration wizard");
  display.setCursor(0, 20);
  
  display.println("Please press the key");
  display.setCursor(0, 28);
  display.println("at the far right of");
  display.setCursor(0, 36);
  display.println("the third row.");
  display.display();
  display.setCursor(0, 50);

  while(1){
    if(gpio_get(23) == 0){
      display.println("HW version is 1.01.");
      result = 101;
      break;
    }
    else if(gpio_get(25) == 0){
      display.println("HW version is 1.00.");
      result = 100;
      break;
    }
  }

  display.display();
  return result;
}

void calibrationMagLevRange(){
  adc_init();
  adc_gpio_init(26);
  adc_gpio_init(29);
  adc_gpio_init(28);
  adc_gpio_init(27);
  
  display.clearDisplay();
  display.setTextColor(WHITE);
  display.setCursor(0, 10);
  display.println("Please stay away from keys and press the menu button.");
  while(gpio_get(13)){
    delay(50);
  }

  
  display.clearDisplay();
  display.setTextColor(WHITE);
  display.setCursor(0, 10);
  display.println("Please press the A key until the bottom, then release it and press the menu button");
  while(gpio_get(13)){
    delay(50);
  }
}

void clear_gpio(uint pin) {
    gpio_init(pin);
    gpio_set_dir(pin, GPIO_IN);
    gpio_disable_pulls(pin);
}

void resetWizard(){
  // A menu button initialization
  gpio_init(13);
  gpio_pull_up(13);
  gpio_set_dir(13, GPIO_IN);
  
  absolute_time_t switching_delay_time = make_timeout_time_us(75);
  sleep_until(switching_delay_time);

  display.clearDisplay();

  if(gpio_get(13) == 0){
    display.setTextColor(WHITE);
    display.setCursor(0, 10);
    display.println("Press the menu button to reset settings.");
    display.display();
    
    // wait until the button released
    while(gpio_get(13) == 0){
      delay(50);
    }

    // wait until the button pressed
    while(gpio_get(13)){
      delay(50);
    }

    // erase settings
    eraseSettings();
  }
  clear_gpio(13);

  return;
}

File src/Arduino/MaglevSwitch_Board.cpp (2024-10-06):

#include "MaglevSwitch_Board.h"
#include <cstring>

MaglevSwitchBoard::MaglevSwitchBoard()
  : SW_NUM        (SW_NUM_DEFAULT),
  DIRECT_SW_NUM   (DIRECT_SW_NUM_DEFAULT),
  MATRIX_OUT_NUM  (MATRIX_OUT_NUM_DEFAULT),
  MATRIX_IN_NUM   (MATRIX_IN_NUM_DEFAULT),
  SW_GPIO         (nullptr),
  MATRIX_OUT_GPIO (nullptr),
  MATRIX_IN_GPIO  (nullptr),
  STATUS_BITS     (nullptr),
  STATUS_BITS_SW    (nullptr)
  {};

MaglevSwitchBoard::MaglevSwitchBoard(uint16_t version, char* swCodesLayer1, char* swCodesLayer2, 
  ThresholdData* actuationDepth, ThresholdData* releaseDepth, uint8_t* outCodes)
  : SW_NUM        ((version == 100) ? SW_NUM_100          : (version == 101) ? SW_NUM_101           : SW_NUM_DEFAULT),
  DIRECT_SW_NUM   ((version == 100) ? DIRECT_SW_NUM_100   : (version == 101) ? DIRECT_SW_NUM_101    : DIRECT_SW_NUM_DEFAULT),
  MATRIX_OUT_NUM  ((version == 100) ? MATRIX_OUT_NUM_100  : (version == 101) ? MATRIX_OUT_NUM_101   : MATRIX_OUT_NUM_DEFAULT),
  MATRIX_IN_NUM   ((version == 100) ? MATRIX_IN_NUM_100   : (version == 101) ? MATRIX_IN_NUM_101    : MATRIX_IN_NUM_DEFAULT),
  SW_GPIO         ((version == 100) ? SW_GPIO_100         : (version == 101) ? SW_GPIO_101          : nullptr),
  MATRIX_OUT_GPIO ((version == 100) ? MATRIX_OUT_GPIO_100 : (version == 101) ? MATRIX_OUT_GPIO_101  : nullptr),
  MATRIX_IN_GPIO  ((version == 100) ? MATRIX_IN_GPIO_100  : (version == 101) ? MATRIX_IN_GPIO_101   : nullptr),
  STATUS_BITS     ((version == 100) ? STATUS_BITS_100     : (version == 101) ? STATUS_BITS_101      : nullptr), 
  STATUS_BITS_SW  ((version == 100) ? STATUS_BITS_SW_100  : (version == 101) ? STATUS_BITS_SW_101   : nullptr)
  {
    outCodes_ = outCodes;

    switchGpioInit(); 

    actuationDepth_ = actuationDepth;
    releaseDepth_ = releaseDepth;

    for(int i = 0; i <MLSW_NUM; i++){
      currentDepth_[i]      = 0;
      pressedPrev_[i]       = false;
    }
    
    rotaryEncoderInit();
    i2cInit();

    fnSw_   = -1;

    switchStatusBits_ = 0;
    switchStatusBitsPrev_ = 0;

    for(uint8_t i = 0; i < SW_NUM; i++){
      swCodesLayer1_[i] = swCodesLayer1[i];
      swCodesLayer2_[i] = swCodesLayer2[i];
      if(swCodesLayer1[i] == FN){
        fnSw_ = i;
      }
    }
    
    swCodes_      = swCodesLayer1_;
}

bool MaglevSwitchBoard::switchGpioInit(void){
    for(int i = 0; i < DIRECT_SW_NUM; i++){
      gpio_init(SW_GPIO[i]);
      gpio_pull_up(SW_GPIO[i]);
      gpio_set_dir(SW_GPIO[i], GPIO_IN);
    }
    
    for(int i = 0; i < MATRIX_IN_NUM; i++){
      gpio_init(MATRIX_IN_GPIO[i]);
      gpio_pull_up(MATRIX_IN_GPIO[i]);
      gpio_set_dir(MATRIX_IN_GPIO[i], GPIO_IN);
    }
    for(int i = 0; i < MATRIX_OUT_NUM; i++){
      gpio_init(MATRIX_OUT_GPIO[i]);
      gpio_set_dir(MATRIX_OUT_GPIO[i], GPIO_OUT);
    }
    
    adc_init();

    for(int i = 0; i <MLSW_NUM; i++){
      adc_gpio_init(MLSW_GPIO[i]);
    }

    return true;
}

bool MaglevSwitchBoard::rotaryEncoderInit(){
  gpio_init(ENCODER_A);
  gpio_pull_up(ENCODER_A);
  gpio_set_dir(ENCODER_A, GPIO_IN);

  gpio_init(ENCODER_B);
  gpio_pull_up(ENCODER_B);
  gpio_set_dir(ENCODER_B, GPIO_IN);
  
  gpio_init(ENCODER_SW);
  gpio_pull_up(ENCODER_SW);
  gpio_set_dir(ENCODER_SW, GPIO_IN);

  return true;
}

bool MaglevSwitchBoard::i2cInit(){
  gpio_set_function(2, GPIO_FUNC_I2C);
  gpio_set_function(3, GPIO_FUNC_I2C);
  gpio_pull_up(2);
  gpio_pull_up(3);

  return true;
}

bool MaglevSwitchBoard::updateState(void){
  switchStatusBitsPrev_ = switchStatusBits_;
  switchStatusBits_ = 0;

  updateEncoderSwitch();
  updateAnalogueSwitch();
  updateDigitalSwitch();
  updateMatrix(); // it takes a 75us * number of rows

  makeSendCodes();

  if(outCodesCnt_ > 0){
    return true;
  }
  return false;
}

void MaglevSwitchBoard::updateEncoderSwitch(){
  if(!gpio_get(ENCODER_SW)){
    encoderSwPressed_ = true;
  }
  else{
    encoderSwPressed_ = false;
  }
}

void MaglevSwitchBoard::updateAnalogueSwitch(){
  for(int i = 0; i < MLSW_NUM; i++){
    prevDepth_[i] = currentDepth_[i];
    adc_select_input(ADC_NUM[i]);
    currentDepth_[i] = adc_read();

    if(isPressed(i)){
      switchStatusBits_ |= STATUS_BITS_MLSW[i];
    }
  }
}

void MaglevSwitchBoard::updateDigitalSwitch(){
  for(int i = 0; i < DIRECT_SW_NUM; i++){
    if(!gpio_get(SW_GPIO[i])){
      switchStatusBits_ |= STATUS_BITS_SW[i];
    }
  }
}

void MaglevSwitchBoard::updateMatrix(){
  for(uint8_t i = 0; i < MATRIX_OUT_NUM; i++){
    gpio_put(MATRIX_OUT_GPIO[i], 0);
    absolute_time_t switching_delay_time = make_timeout_time_us(75);
    sleep_until(switching_delay_time);

    for(uint8_t j = 0; j < MATRIX_IN_NUM; j++){
      if(!gpio_get(MATRIX_IN_GPIO[j])){
        switchStatusBits_ |= STATUS_BIT_MATRIX[i][j];
      }
    }
    gpio_put(MATRIX_OUT_GPIO[i], 1);
  }
}
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

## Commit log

2024-04-29 First version
    First version(no outer shells).
    [Reference_Keyboard.kicad_pcb, Reference_Keyboard.kicad_sch, SSD1306_FFC_Adapter.kicad_pcb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]
2024-05-16 rollback debug display and minor fixes
    [Arduino.ino]
2024-05-16 Add the adjustable actuation point and the release point of switches
2024-05-23 Fix quick release function
    [MaglevSwitch_Board.cpp]
2024-05-24 Add 3d models
    [BottomCase.3mf, Knob.3mf, Stand.3mf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]
2024-06-01 Bug fix for the Fn key
    [Reference_Keyboard.kicad_pcb, Reference_Keyboard.kicad_sch]
2024-07-13 add firmware and PCB for hardware v1.01
    [BottomCase.3mf, Reference_Keyboard.kicad_pcb, Reference_Keyboard.kicad_sch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]
2024-08-25 Add 3d models for hardweare v1.01
    [BottomCase.3mf, Knob.3mf, Stand.3mf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]
2024-10-06 Add a current protection circuit
    [Reference_Keyboard.kicad_pcb, Reference_Keyboard.kicad_sch, TopPlate.3mf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]
2024-10-07 Fix typo & change version on the logo
    [Arduino.ino]
2024-11-24 Update 3d models
    [Assy.step, BottomCase.3mf, Knob.3mf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]
2024-12-19 change the poly-fuse
    [Reference_Keyboard.kicad_pcb]
2025-03-28 Update readme, directories, and 3d models
    [Assy.step, BottomCase.3mf, BottomSwitchCap.3mf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]
